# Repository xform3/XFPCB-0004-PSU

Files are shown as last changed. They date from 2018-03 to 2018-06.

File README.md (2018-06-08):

Xform3

# XFPCB-0004 Regulated Bipolar Dual Voltage AC to ±DC Power Supply  
Dual ±DC Output Power Supply, built around LM79XX & LM18XX regulators. This power supply is intended to be used with VAC center tapped transformer for audio/amplifier applications.

## Specifications 
(±18VDC Example)
- Input Voltage:  18-0-18 VAC 1A @ 47-63Hz
- Output Voltage: +18 VDC | 0 VDC | -18 VDC
- Throught-hole components, single-layer clad.

## Features
- Input Voltage Filtering
- Low Output Ripple, Voltage Stable to ±0.005VDC

## Variations 
(By replacing LM78xx & LM79xx Voltage can be adjusted respectively)
* 6V-0-6V (12W)   - LM7906 & LM7806
* 12V-0-12V (24W) - LM7912 & LM7812
* 15V-0-15V (30W) - LM7915 & LM7816
* 18V-0-18V (36W) - LM7918 & LM7818

## [Compatible with XFPCB-0003_AMP Class-AB Amplifier](https://github.com/xform3/xfpcb-0003-amp)

## Included Files:
* [xf3_psu](https://github.com/xform3/XFPCB-0004-PSU/tree/master/xf3_psu)  - *KiCAD Project Files*
* [xf3_psu_mask](https://github.com/xform3/XFPCB-0004-PSU/tree/master/xf3_psu_mask) - *PCB Gerber, Drill, Silk/Solder Masks, Positive and Negative plots*
* [xf3-KiCad-Library](https://github.com/xform3/xf3-KiCad-Library)  - *KiCAD Library Files; footprints, .step and .wrl component models, schema lib.*

## Application:
(±18VDC Example)
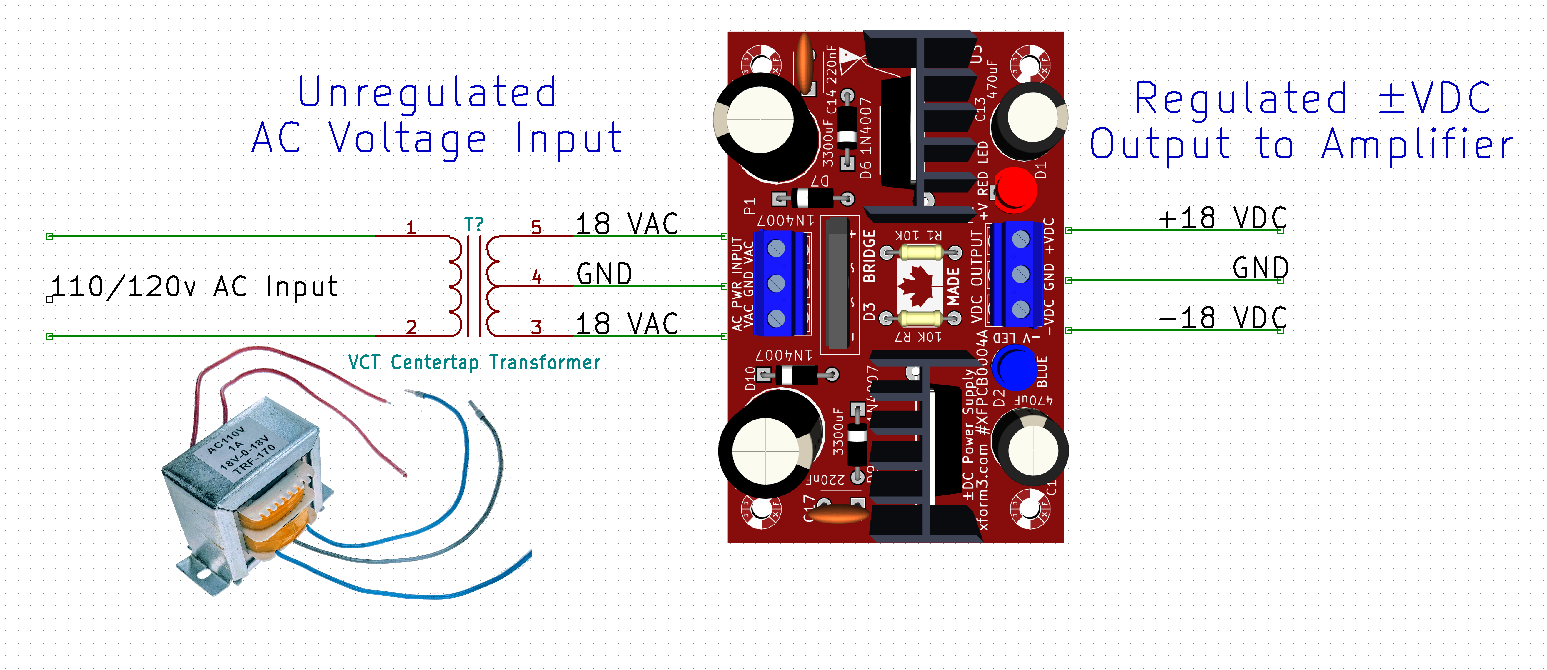
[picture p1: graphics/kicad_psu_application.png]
Xform3 XFPCB-0004 Bipolar Power Supply Application


## Schematic
(±18VDC Example)
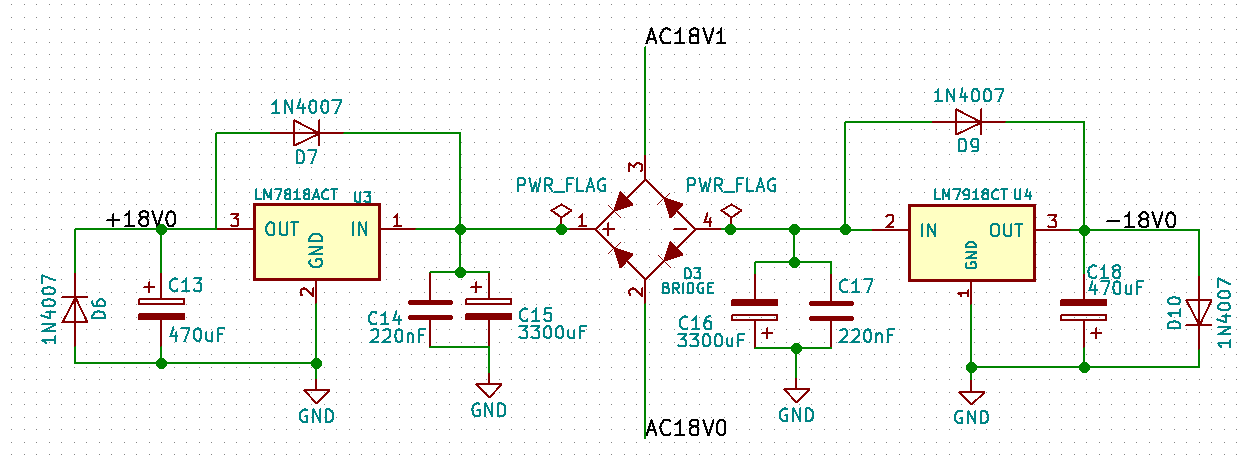
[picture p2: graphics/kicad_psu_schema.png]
Xform3 XFPCB-0004 Bipolar Power Supply KiCAD Schema


## PCB
(±18VDC Example)
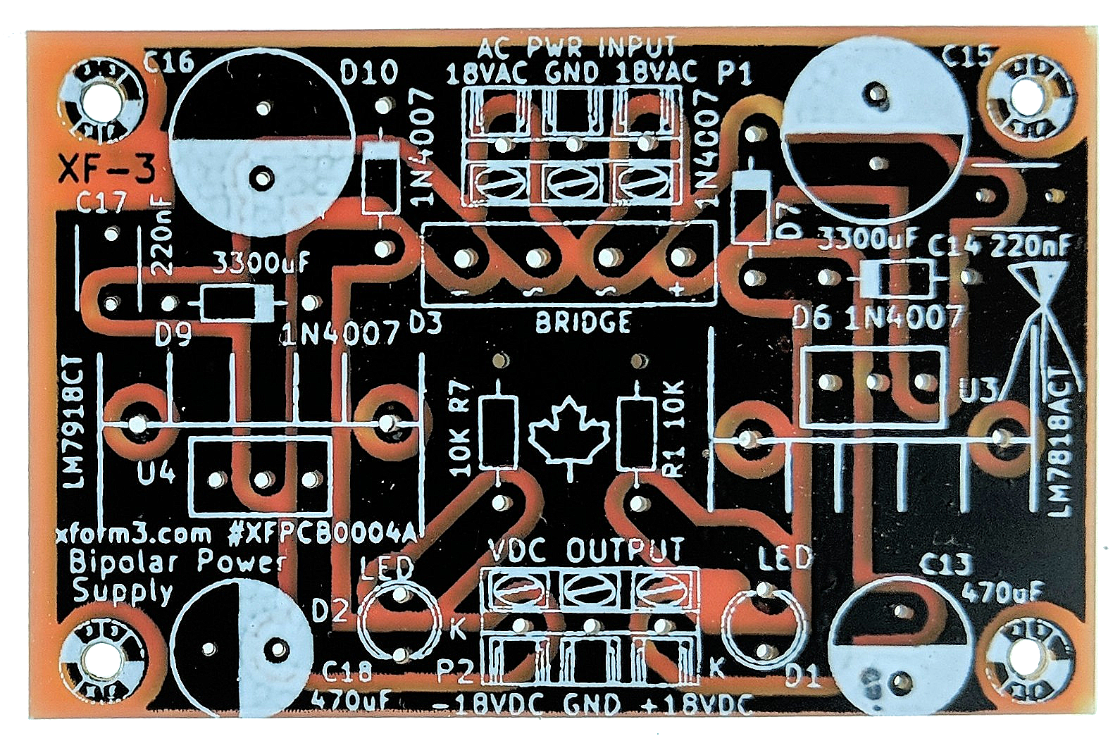
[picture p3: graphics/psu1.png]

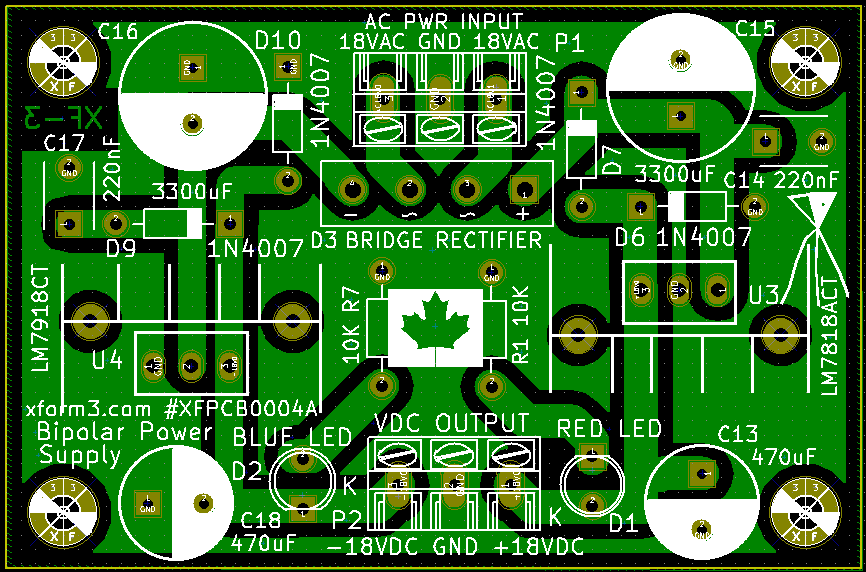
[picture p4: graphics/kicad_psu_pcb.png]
Xform3 XFPCB-0004 Bipolar Power Supply KiCAD PCB


## PROTOTYPE
Xform3 XFPCB-0004 Bipolar Power Supply PROTOTYPE
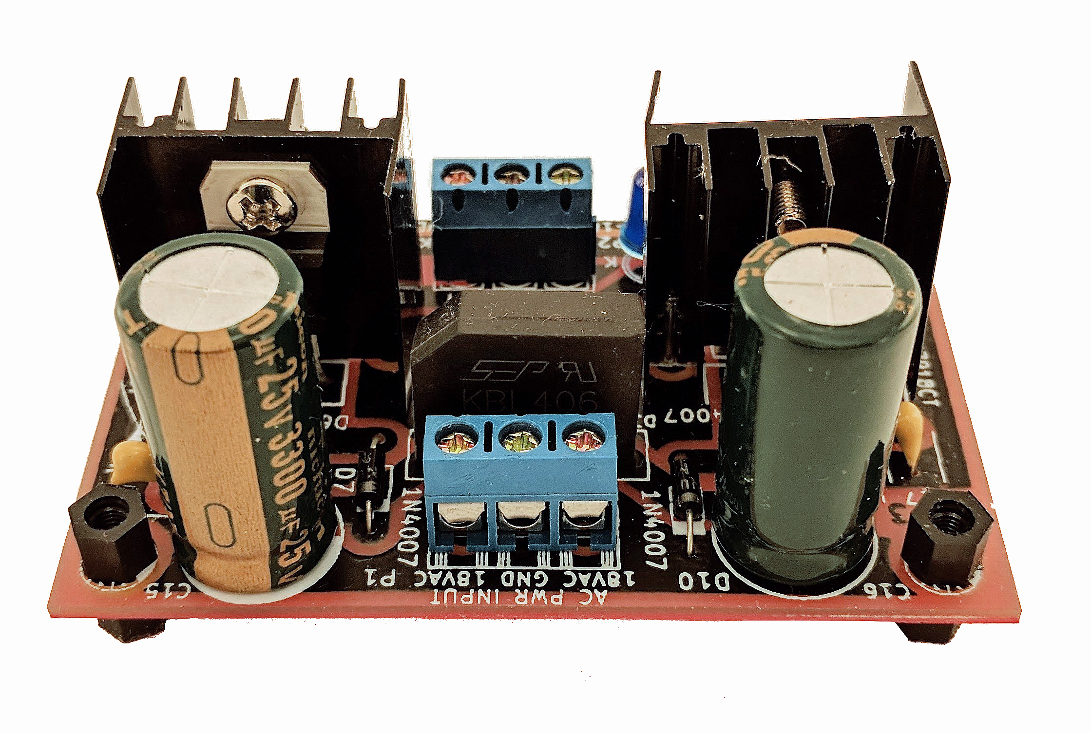
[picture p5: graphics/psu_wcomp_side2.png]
Xform3 XFPCB-0004 Bipolar Power Supply PROTOTYPE

Xform3 XFPCB-0004 Bipolar Power Supply PROTOTYPE

## KiCad 3D
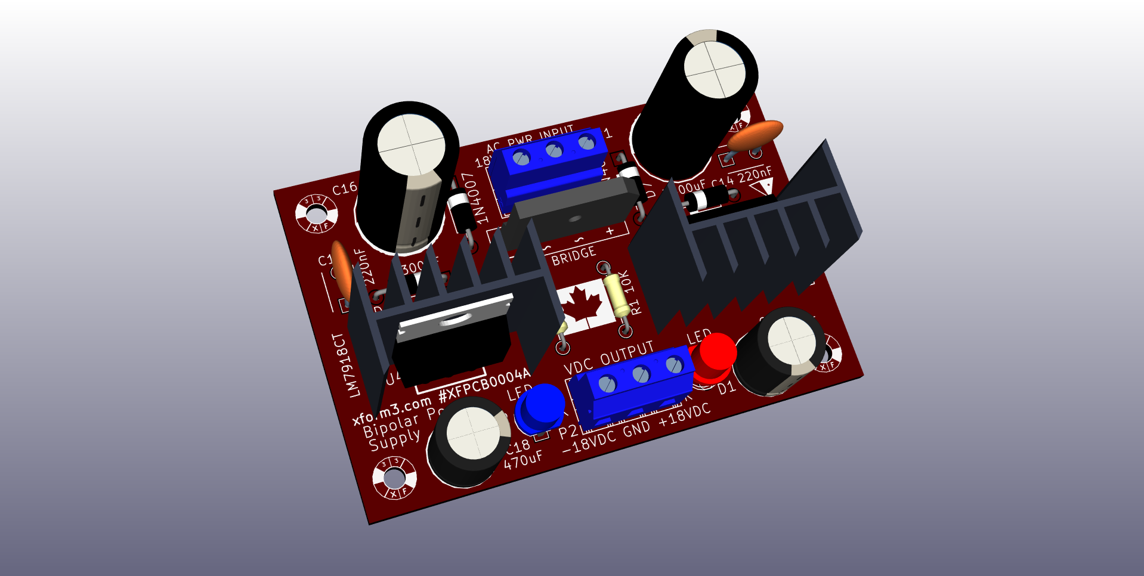
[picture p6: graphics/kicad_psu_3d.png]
Xform3 XFPCB-0004 Bipolar Power Supply KiCad 3d


## FreeCAD Model
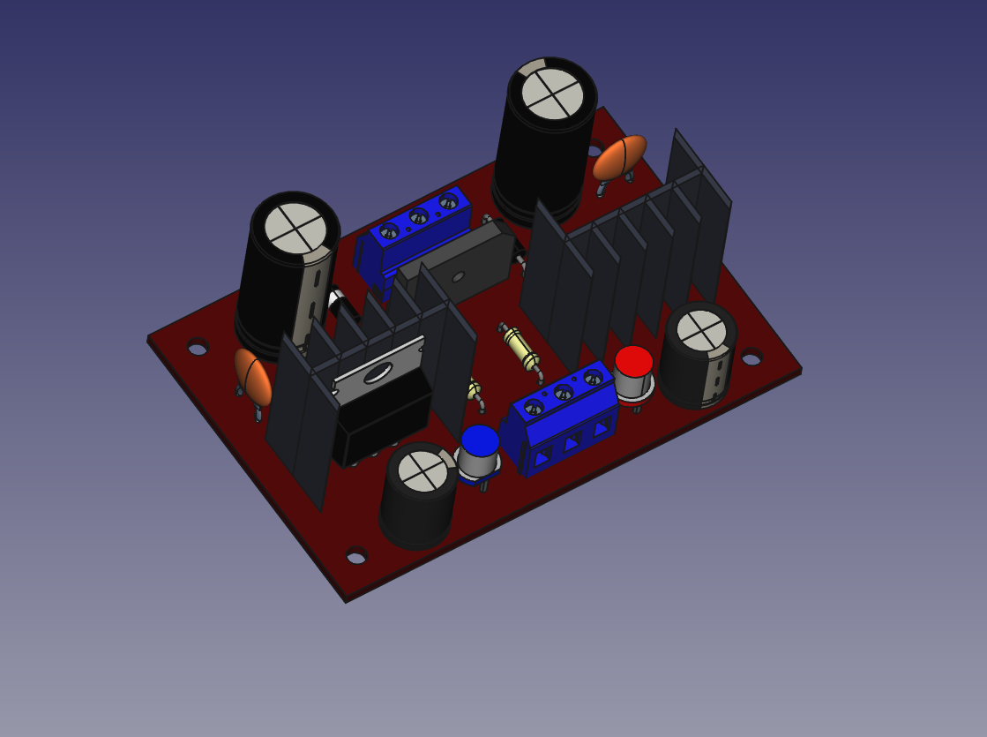
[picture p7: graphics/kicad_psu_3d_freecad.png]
Xform3 XFPCB-0004 Bipolar Power Supply FreeCAD Model


## VCT Center tap Transformer
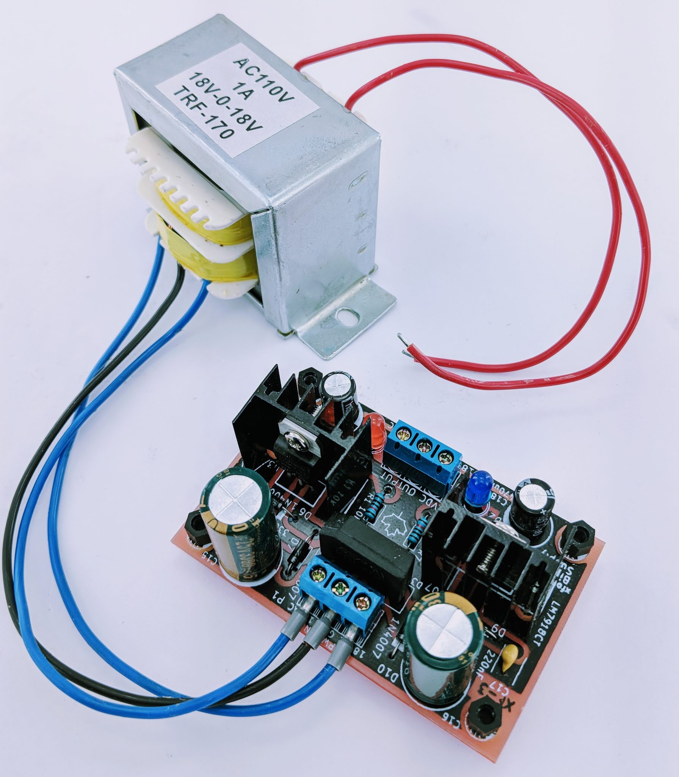
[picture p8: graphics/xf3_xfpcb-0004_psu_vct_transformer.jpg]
Xform3 XFPCB-0004 Bipolar Power Supply Application


## Amplifier [Using: XFPCB-0003 Class-AB Amplifier 20-30W LM1875 or TDA2030](https://github.com/xform3/xfpcb-0003-amp)
Xform3 XFPCB-0003 Class-AB Amplifier
Xform3 XFPCB-0003 Class-AB Amplifier

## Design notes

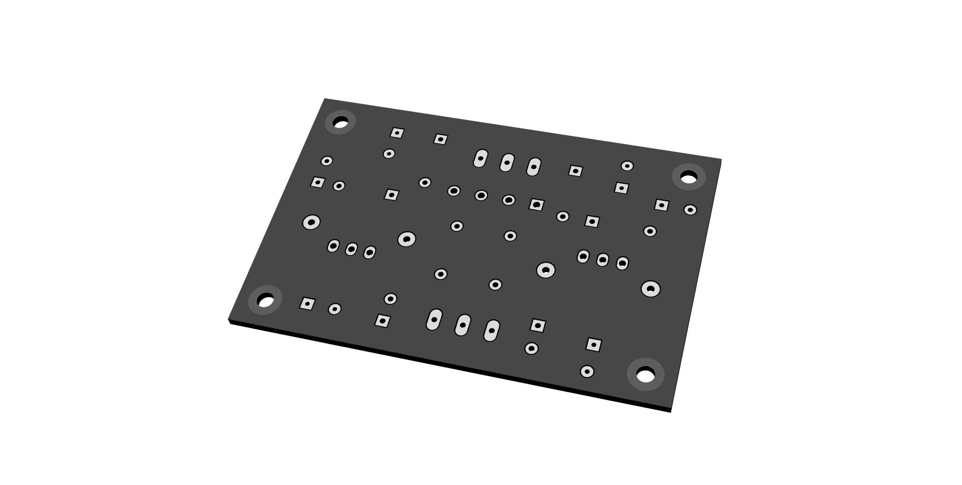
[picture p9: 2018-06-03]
graphics/xf3_PSU_size.png

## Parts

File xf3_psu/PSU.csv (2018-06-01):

Title
Revision
Date | 2018-03-14
Generated | Sat 19 May 2018 01:26:42 AM EDT
Company
Comment 1
Comment 2
Comment 3
Comment 4
Total Parts | 23
Total Unique Parts | 13
Ref | Qty | Value | Footprint | Datasheet
C13 C18 | 2 | 470uF | x_components:x_CapRadial10mm
C14 C17 | 2 | 220nF | x_components:x_CapDisk9mm
C15 C16 | 2 | 3300uF | x_components:x_CapRadial13mm
D1 | 1 | LED | x_components:x_Led
D2 | 1 | LED | x_components:x_LedBlue
D3 | 1 | BRIDGE | x_components:x_DiodeBridge
D6 D7 D9 D10 | 4 | 1N4007 | x_components:x_Diode
P1 | 1 | CONN_01X03 | x_components:x_PhoenixX3flipped
P2 | 1 | CONN_01X03 | x_components:x_PhoenixX3
P3 P4 P5 P6 | 4 | xhole | x_components:x_HoleRound
R1 R7 | 2 | 10K | x_components:x_ResistorHorizontalRM10mm
U3 | 1 | LM7818ACT | x_components:x_TO220Heatsink
U4 | 1 | LM7918CT | x_components:x_TO220Heatsink
BOM made with KICAD_BOM_WIZARD (https://github.com/HashDefineElectronics/KiCad_BOM_Wizard.git)
Generated Sat 19 May 2018 01:26:42 AM EDT

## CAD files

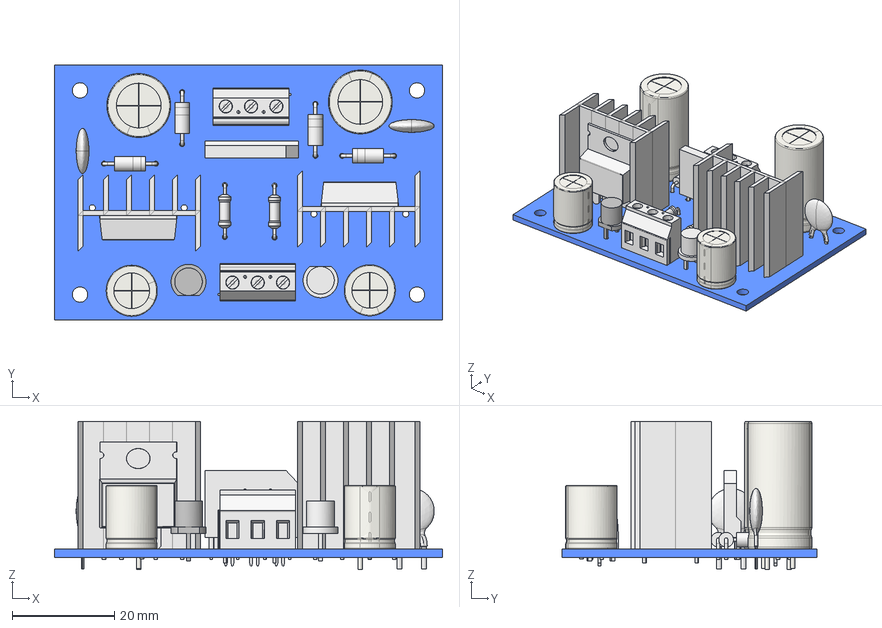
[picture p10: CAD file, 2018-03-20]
graphics/PSU.FCStd
76.0 x 50.0 x 29.0 mm
Pcb
x_CapRadial10mm_
x_TO220Heatsink2_
x_Diode_
x_CapRadial13mm_
x_CapRadial13mm_001
x_TO220Heatsink2_001
x_Diode_001
x_Diode_002
x_Diode_003
x_DiodeBridge_
x_CapDisk9mm_
x_CapDisk9mm_001
x_Led_
x_LedBlue_
x_ResistorHorizontalRM10mm_
x_ResistorHorizontalRM10mm_001
x_CapRadial10mm_001
x_Phoenix3_
x_Phoenix3_001

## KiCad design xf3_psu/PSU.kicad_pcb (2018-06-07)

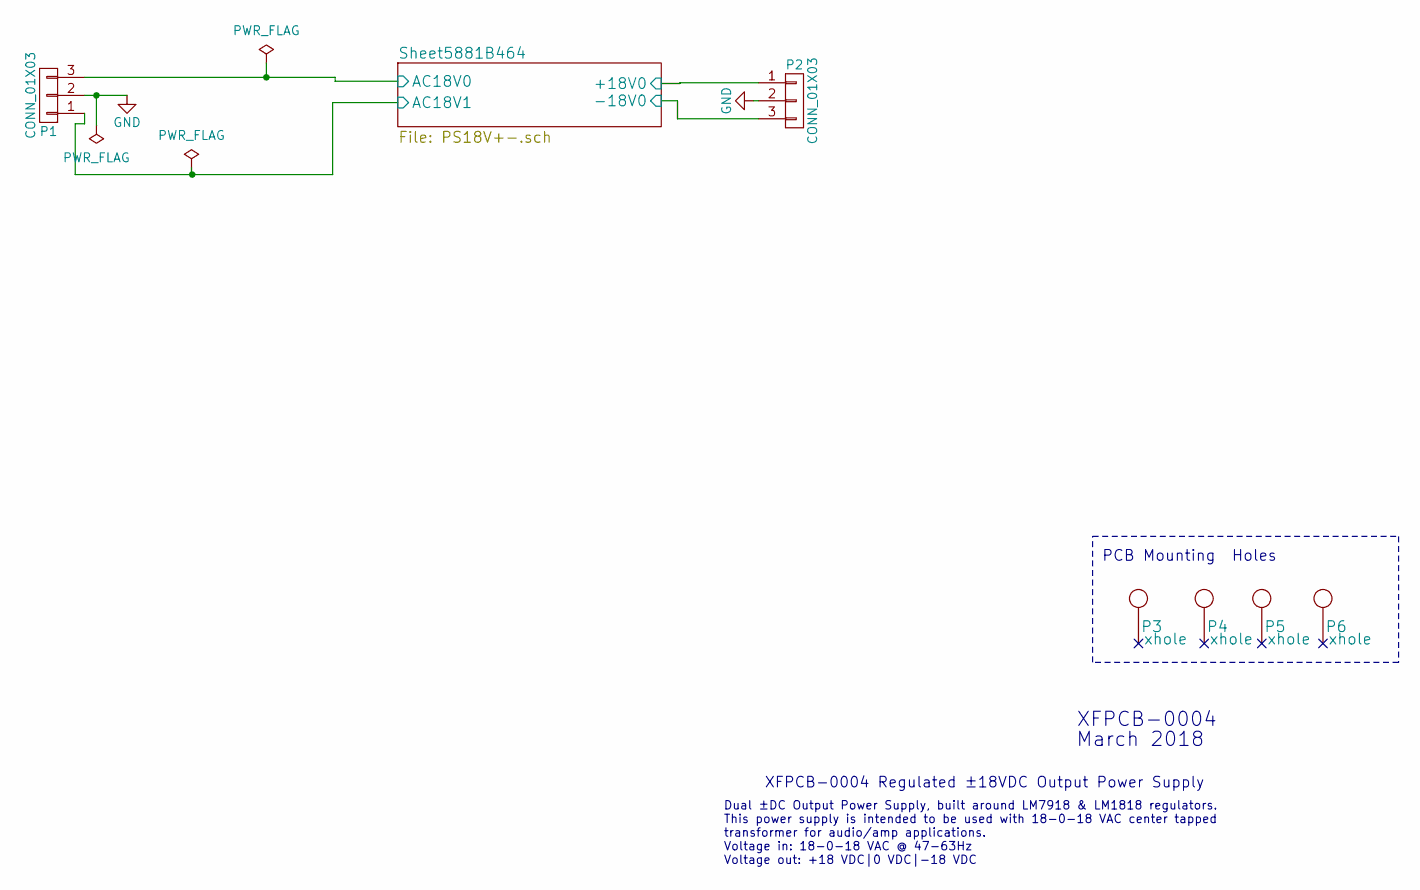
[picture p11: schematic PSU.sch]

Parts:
P1: CONN_01X03; x_PhoenixX3flipped
P2: CONN_01X03; x_PhoenixX3
P3, P4, P5, P6: xhole; x_HoleRound

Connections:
/Sheet5881B464/+18V0: P2.1; also elsewhere on the board
/Sheet5881B464/-18V0: P2.3; also elsewhere on the board
/Sheet5881B464/AC18V0: P1.3; also elsewhere on the board
/Sheet5881B464/AC18V1: P1.1; also elsewhere on the board
GND: P1.2, P2.2; also elsewhere on the board

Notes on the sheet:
Dual ±DC Output Power Supply, built around LM7918 & LM1818 regulators. This power supply is intended to be used with 18-0-18 VAC center tapped transformer for audio/amp applications. Voltage in: 18-0-18 VAC @ 47-63Hz Voltage out: +18 VDC|0 VDC|-18 VDC
XFPCB-0004 Regulated ±18VDC Output Power Supply
XFPCB-0004
March 2018
PCB Mounting Holes

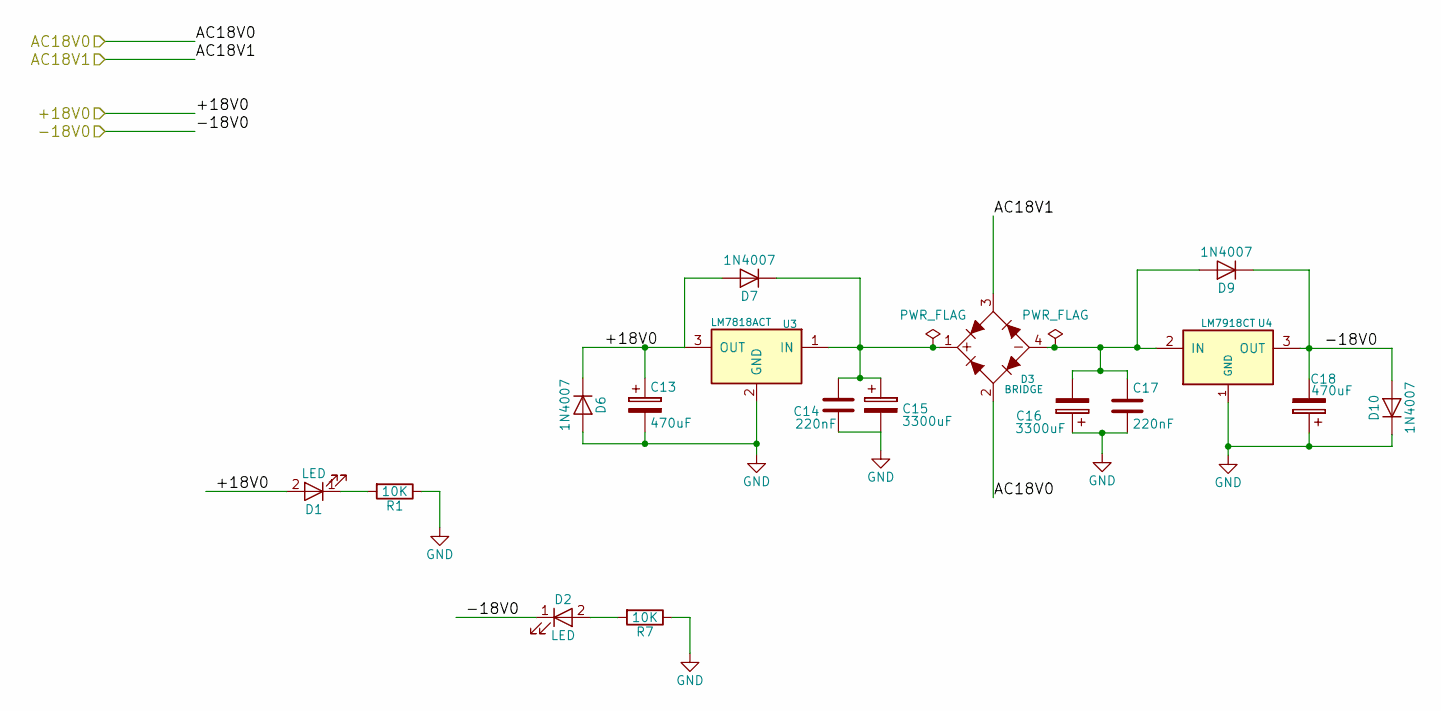
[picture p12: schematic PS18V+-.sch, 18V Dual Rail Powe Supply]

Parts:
C13, C18: 470uF; x_CapRadial10mm
C14, C17: 220nF; x_CapDisk9mm
C15, C16: 3300uF; x_CapRadial13mm
D1: LED; x_Led
D2: LED; x_LedBlue
D3: BRIDGE; x_DiodeBridge
D6, D7, D9, D10: 1N4007; x_Diode
R1, R7: 10K; x_ResistorHorizontalRM10mm
U3: LM7818ACT; x_TO220Heatsink
U4: LM7918CT; x_TO220Heatsink

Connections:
/Sheet5881B464/+18V0: C13.1, D1.2 (A), D6.1 (K), D7.2 (A), U3.3 (OUT); also elsewhere on the board
/Sheet5881B464/-18V0: C18.2, D2.1 (K), D9.1 (K), D10.2 (A), U4.3 (OUT); also elsewhere on the board
/Sheet5881B464/AC18V0: D3.2 (~1); also elsewhere on the board
/Sheet5881B464/AC18V1: D3.3 (~2); also elsewhere on the board
GND: C13.2, C14.2, C15.2, C16.1, C17.2, C18.1, D6.2 (A), D10.1 (K), R1.1, R7.1, U3.2 (GND), U4.1 (GND); also elsewhere on the board
unnamed: C14.1, C15.1, D3.1 (V+), D7.1 (K), U3.1 (IN)
unnamed: C16.2, C17.1, D3.4 (V-), D9.2 (A), U4.2 (IN)
unnamed: D1.1 (K), R1.2
unnamed: D2.2 (A), R7.2

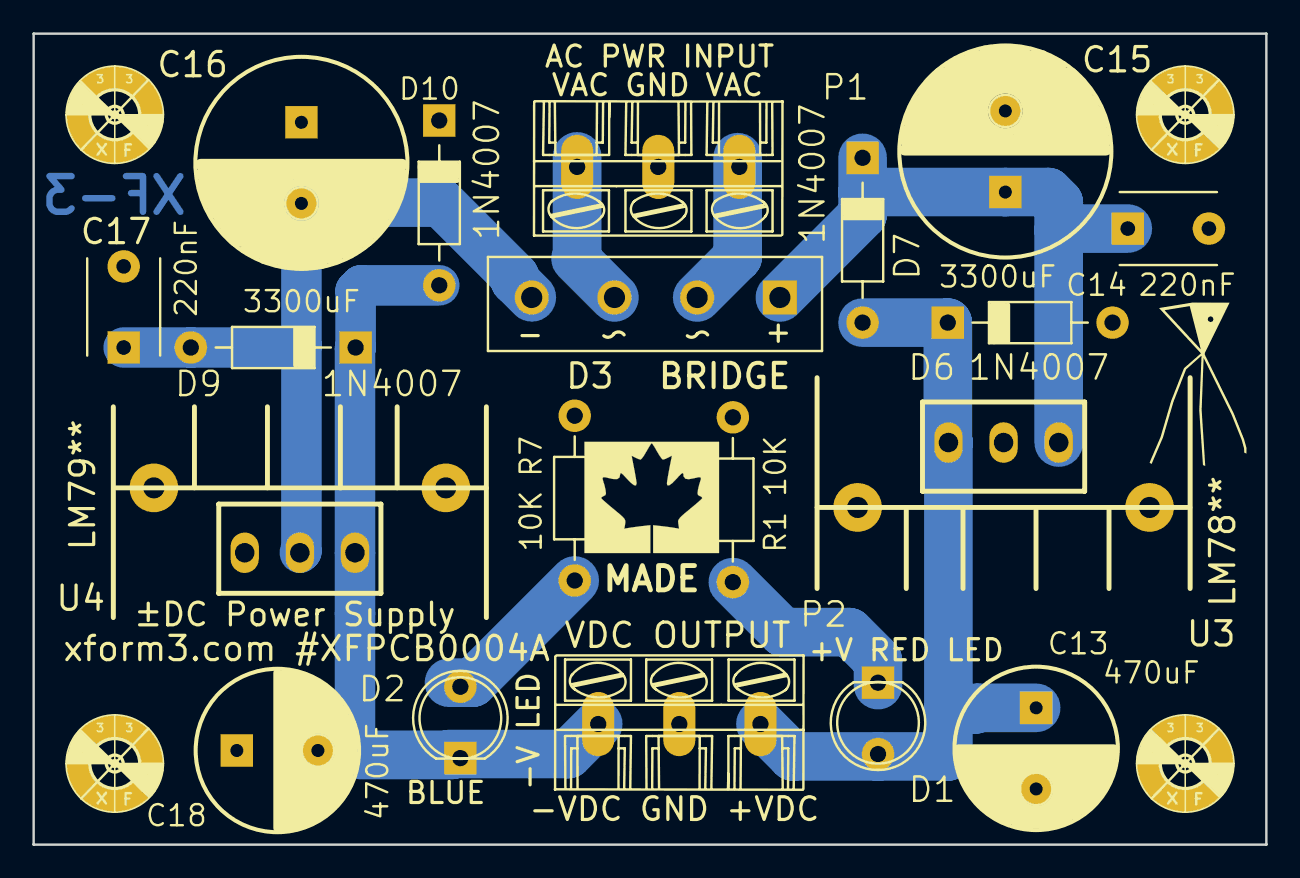
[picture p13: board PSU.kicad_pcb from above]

Board: 2 copper layers, 76.0 x 50.0 mm, 24 parts (0 on the bottom side), 9 nets.

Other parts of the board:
svg2mod: G***; x_gx_xform_5x8_Silk

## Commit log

2018-03-20 Name corrections
    [PSU-B.Cu.gbr, PSU-B.Mask.gbr, PSU-F.SilkS.gbr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]
2018-06-01 adds photos, silkscreen changes
    [PSU.csv]
2018-06-03 silkscreen edits
2018-06-03 silkscreen changes
    [PSU.kicad_pcb]
2018-06-07 fixed silk, changed graphics
    [PSU.kicad_pcb]
